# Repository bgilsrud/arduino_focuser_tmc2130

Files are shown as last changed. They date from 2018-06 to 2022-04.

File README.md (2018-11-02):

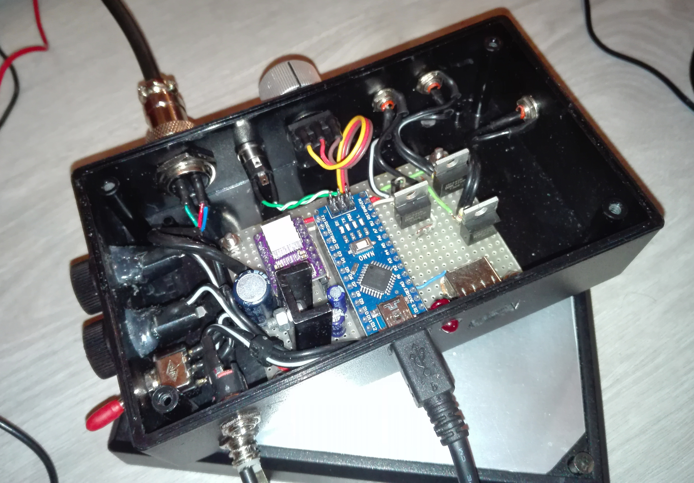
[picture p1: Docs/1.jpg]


# Arduino-based telescope focuser controller
Simple MoonLite-compatible motorized focuser controller. Thought to be used with INDI.
Doesn't support temperature compensation.
It also supports a non-official MoonLite-style command to change the state of all the
Arduino's digital and PWM pins: in my case I control two dew heaters and a fan to cool the primary mirror.

### MoonLite focuser
I use a Nema 11 motor that moves the focuser knob using a belt.
If you don't have a heavy focuser, also consider using a Nema 8.
A 20 teeth pulley and a 6mm wide 160mm long belt are enough.
Absolute and relative positioning, half and full step switching.

### Pin management
Define the customizable pins in the `CUSTOMIZABLE_PINS` array in the `Config.h` file and
upload the firmware.

#### AstroAllInOne
<a href="https://github.com/SquareBoot/AstroAllInOne">AstroAllInOne</a>
is this firmware's companion INDI driver that allows the end user to
change the state of **every** pin of the board (pay attention! **do not change the
state of the stepper motor driver's pins**). Refer to its documentation on
how to configure it. Without AstroAllInOne, the Arduino will behave just like
a generic MoonLite focuser controller.

### Polar finder illuminator
For my EQ5 I needed an illuminator and I added it to the focuser project.
It requires a potentiometer to dim the light and a red LED.
Can be easily disabled in the `Config.h` file by setting the `ENABLE_POLAR_LIGHT` field.

### Autodesk Eagle project
In the "Eagle" directory you can find the full circuit project, both schematics and PCB. 
It's the one I use for my telescope, but feel free to modify it to 
accomplish your necessities: for instance, you could add another dew heater controller, 
or remove the Newton mirror cooler MOSFET.
<br>**Made with Eagle 9.2.2 Premium**
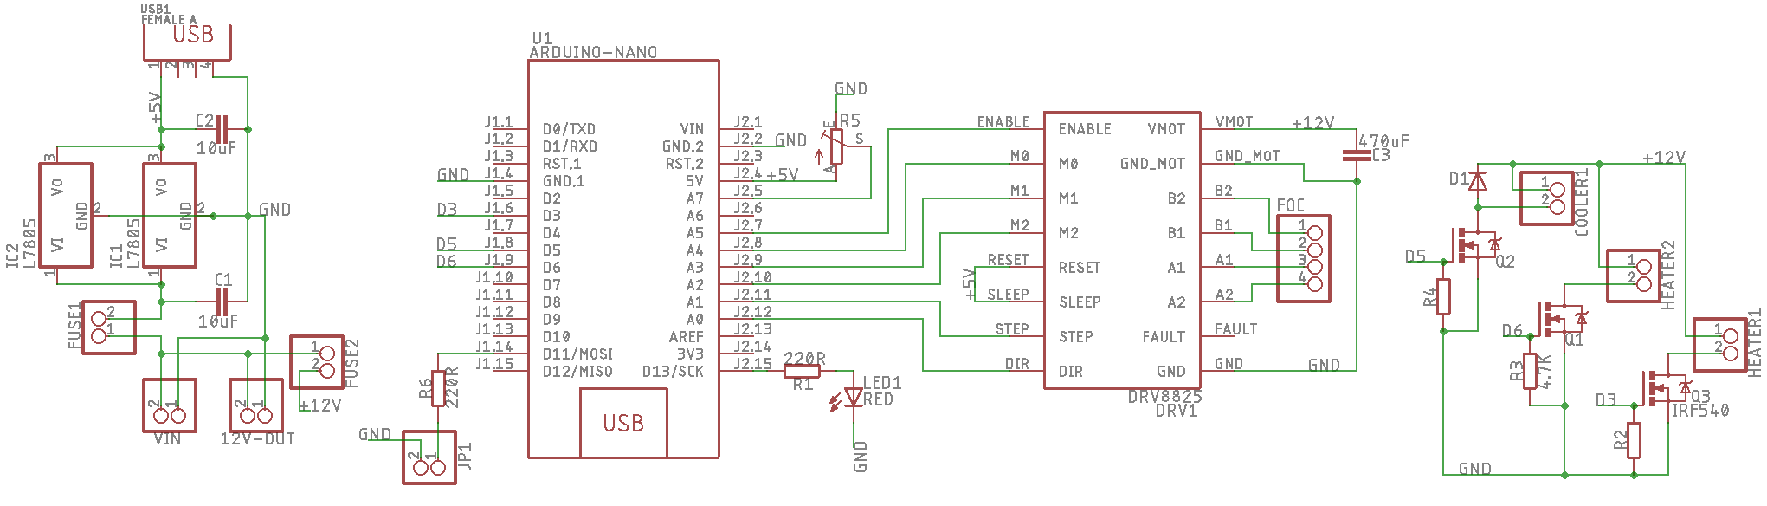
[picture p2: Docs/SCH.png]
<br>

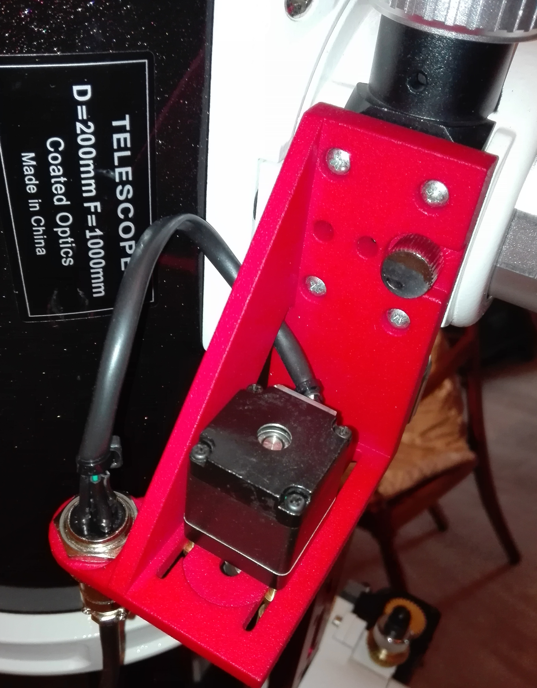
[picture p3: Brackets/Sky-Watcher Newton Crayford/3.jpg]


### Mounting brackets
I included the mounting brackets I made for the common SkyWatcher 
dual-speed Crayford focuser (I have a 200mm f/5 Newton OTA).

**AutoCAD 2019** project, STL and IGS exported files.

### Forking & issues
Feel free to submit pull requests! New brackets are welcome!

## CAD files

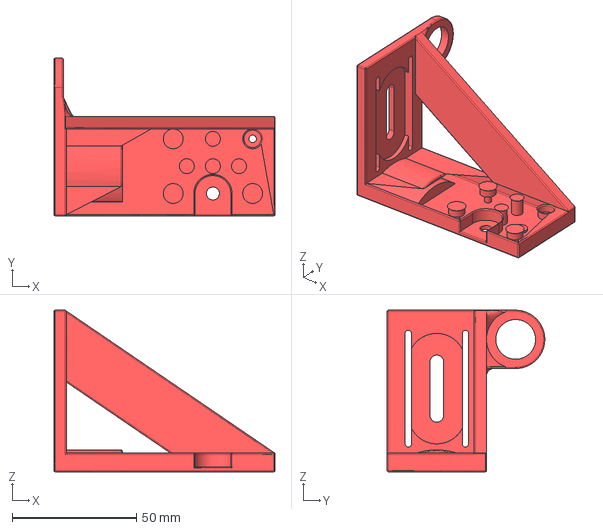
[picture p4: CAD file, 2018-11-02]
Brackets/Sky-Watcher Newton Crayford/IGS.igs
89.0 x 63.5 x 65.1 mm

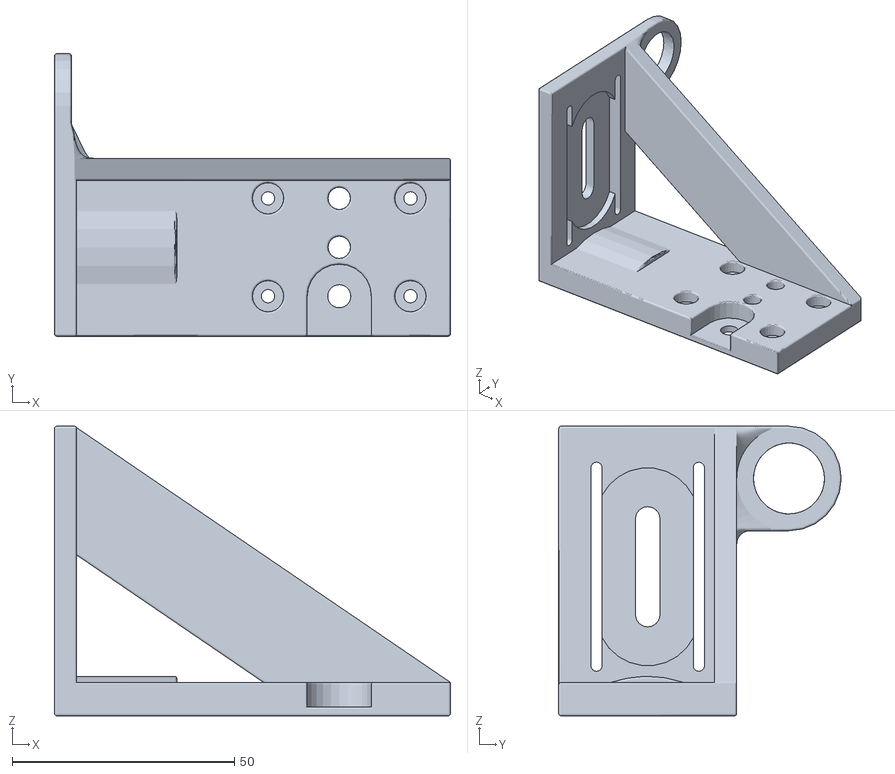
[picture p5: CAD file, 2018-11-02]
Brackets/Sky-Watcher Newton Crayford/STL.stl
89.0 x 63.5 x 65.1

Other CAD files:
Brackets/Sky-Watcher Newton Crayford/AutoCAD.dwg

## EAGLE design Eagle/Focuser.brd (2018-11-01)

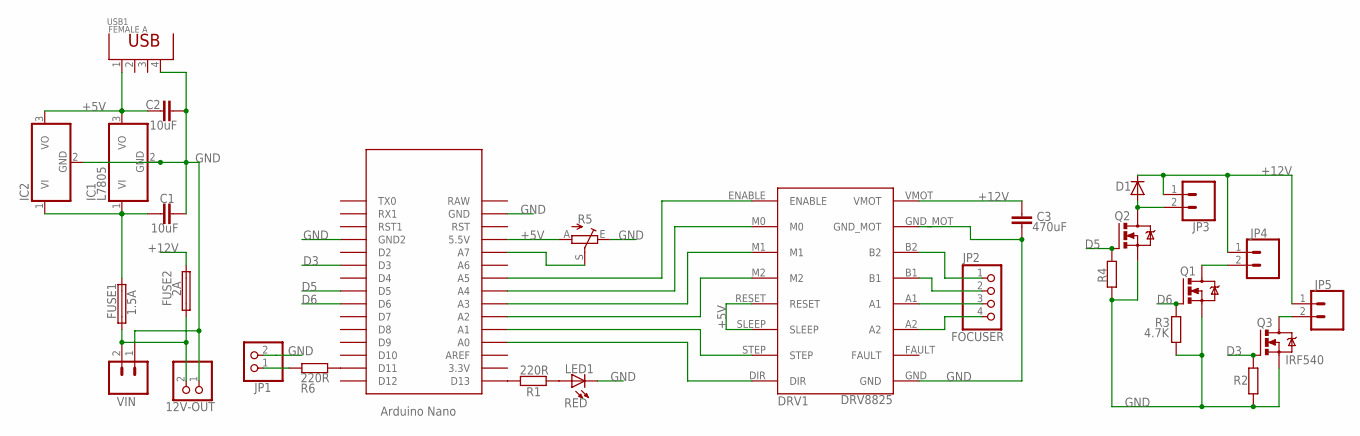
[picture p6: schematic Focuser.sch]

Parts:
12V-OUT: PINHD-1X2; 1X02
C1, C2: 10uF; C025-024X044
C3: 470uF; C5B2.5
D1: DIODE-D-2.5; D-2.5
DRV1: DRV8825
FUSE1: 1.5A; FUSE_HOLDER_5X20MM
FUSE2: 2A; FUSE_HOLDER_5X20MM
IC1, IC2: L7805; TO220V
JP1: PINHD-1X2; 1X02
JP2: FOCUSER; 1X04
JP3, JP4, JP5: CONN_025MM; SCREWTERMINAL-5MM-2
LED1: RED; LED3MM
Q1, Q2, Q3: IRF540; TO220BV
R1, R6: 220R; 0204/5
R2, R3, R4: 4.7K; 0204/5
R5: TRIM_EU-B64Y; B64Y
U$1: NANO
USB1: FEMALE A; USB4+2P-2.0-90D
VIN: CONN_025MM; SCREWTERMINAL-5MM-2

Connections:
+5V: C2.1, DRV1.RESET, DRV1.SLEEP, IC1.3 (VO), IC2.3 (VO), R5.A, U$1.5V (5.5V), USB1.1
+12V: C3.2, D1.C, DRV1.VMOT, FUSE2.2, JP3.1, JP4.1, JP5.1
D3: Q3.G, R2.2, U$1.D3
D5: Q2.G, R4.2, U$1.D5
D6: Q1.G, R3.2, U$1.D6
D13: R1.2, U$1.D13
GND: 12V-OUT.1, C1.2, C2.2, C3.1, DRV1.GND, DRV1.GND_MOT, IC1.2 (GND), IC2.2 (GND), JP1.2, LED1.K (C), Q1.S, Q2.S, Q3.S, R2.1, R3.1, R4.1, R5.E, U$1.GND, U$1.GND1 (GND2), USB1.4, VIN.1
unnamed: LED1.A, R1.1
unnamed: R5.S, U$1.A7
unnamed: R6.2, U$1.D11
unnamed: C1.1, FUSE1.2, IC1.1 (VI), IC2.1 (VI)
unnamed: DRV1.DIR, U$1.A0
unnamed: DRV1.ENABLE, U$1.A5
unnamed: 12V-OUT.2, FUSE1.1, FUSE2.1, VIN.2
unnamed: D1.A, JP3.2, Q2.D
unnamed: JP4.2, Q1.D
unnamed: JP5.2, Q3.D
unnamed: DRV1.STEP, U$1.A1
unnamed: DRV1.B2, JP2.1
unnamed: DRV1.B1, JP2.2
unnamed: DRV1.A1, JP2.3
unnamed: DRV1.A2, JP2.4
unnamed: DRV1.M2, U$1.A2
unnamed: DRV1.M1, U$1.A3
unnamed: JP1.1, R6.1
unnamed: DRV1.M0, U$1.A4

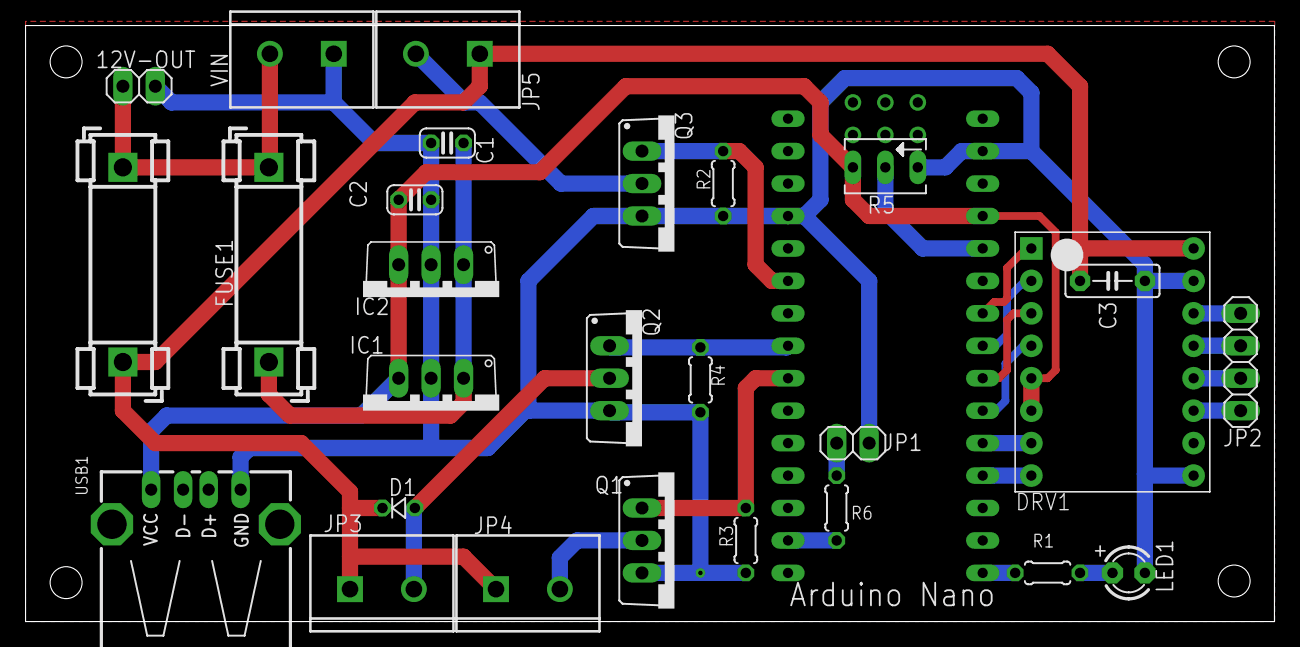
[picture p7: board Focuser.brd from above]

Board: 2 copper layers, 97.8 x 46.7 mm, 28 parts (0 on the bottom side), 26 nets.

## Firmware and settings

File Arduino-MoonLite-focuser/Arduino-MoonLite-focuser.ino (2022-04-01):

/*
  Moonlite-compatible focuser controller

  ** Version 2.2 **
    Bugs fixed, general changes.

  ** Version 2.1 **
    Added function to set pin value.

  ** Version 2.0 **
    Modified to be used with the cheaper DRV8825 (or A4988) driver and almost completely rewritten by SquareBoot

  ** Version 1.0 **
    Inspired by (http://orlygoingthirty.blogspot.co.nz/2014/04/arduino-based-motor-focuser-controller.html)
    Modified for INDI, easydriver by Cees Lensink
    Added sleep function by Daniel Franzén
*/

#include <Arduino.h>

// Firmware version - 2.2
const String VERSION = "22";

// Configuration
#include "Config.h"


// AVR libraries
#if ENABLE_SW_RS == true
#include <avr/io.h>                                       // AVR library
#include <avr/wdt.h>                                      // Watchdog timer
#define reboot() wdt_enable(WDTO_30MS); while(1) {}       // To reset the board, call reboot();
#endif

// Stepper driver libraries
// AccelStepper, used to provide motor acceleration
#include <AccelStepper.h>
#if STEPPER_TYPE == 0
#include <BasicStepperDriver.h>
#elif STEPPER_TYPE == 1
#include <DRV8825.h>
#elif STEPPER_TYPE == 2
#include <A4988.h>
#elif STEPPER_TYPE == 3
#include <DRV8834.h>
#elif STEPPER_TYPE == 4
#include <TMCStepperDriver.h>
#endif

// The period to wait before turning off the driver (in milliseconds)
boolean isRunning = false;
#ifdef DRIVER_EN
#define TIMER_DELAY 30000
boolean isPowerOn = false;
#endif
#if STEPPER_TYPE != 0
boolean isHalfStep = false;
#endif

#ifdef DRIVER_EN
#if STEPPER_TYPE == 0
BasicStepperDriver driver(STEPS_REV, DRIVER_DIR, DRIVER_STEP, DRIVER_EN);
#elif STEPPER_TYPE == 1
DRV8825 driver(STEPS_REV, DRIVER_DIR, DRIVER_STEP, MODE0, MODE1, MODE2, DRIVER_EN);
#elif STEPPER_TYPE == 2
A4988 driver(STEPS_REV, DRIVER_DIR, DRIVER_STEP, MODE0, MODE1, MODE2, DRIVER_EN);
#elif STEPPER_TYPE == 3
DRV8834 driver(STEPS_REV, DRIVER_DIR, DRIVER_STEP, MODE0, MODE1, DRIVER_EN);
#elif STEPPER_TYPE == 4
TMCStepperDriver driver(STEPS_REV, DRIVER_DIR, DRIVER_STEP, Axis1_CS, Axis1_SCK, Axis1_MISO, Axis1_MOSI);
//BasicStepperDriver driver(STEPS_REV, DRIVER_DIR, DRIVER_STEP, DRIVER_EN);

#endif
#else
#if STEPPER_TYPE == 0
BasicStepperDriver driver(STEPS_REV, DRIVER_DIR, DRIVER_STEP);
#elif STEPPER_TYPE == 1
DRV8825 driver(STEPS_REV, DRIVER_DIR, DRIVER_STEP, MODE0, MODE1, MODE2);
#elif STEPPER_TYPE == 2
A4988 driver(STEPS_REV, DRIVER_DIR, DRIVER_STEP, MODE0, MODE1, MODE2);
#elif STEPPER_TYPE == 3
DRV8834 driver(STEPS_REV, DRIVER_DIR, DRIVER_STEP, MODE0, MODE1);
#elif STEPPER_TYPE == 4
TMCStepperDriver driver(STEPS_REV, DRIVER_DIR, DRIVER_STEP, Axis1_CS, Axis1_SCK, Axis1_MISO, Axis1_MOSI);
//BasicStepperDriver driver(STEPS_REV, DRIVER_DIR, DRIVER_STEP);

#endif
#endif

long ml_to_stepper_pos(long ml)
{
    return ml * GEAR_RATIO;
}

long stepper_to_ml_pos(long stepper)
{
    return stepper / GEAR_RATIO;
}

// ----- Motor control wrappers -----
// Forward step
void goForward() {
  int n = SINGLE_STEP;
#if STEPPER_TYPE != 0
  if (isHalfStep) {
    n *= HALF_STEP;

  } else {
    n *= FULL_STEP;
  }
#endif
  driver.move(n);
}
// Backward step
void goBackward() {
  int n = SINGLE_STEP;
#if STEPPER_TYPE != 0
  if (isHalfStep) {
    n *= HALF_STEP;

  } else {
    n *= FULL_STEP;
  }
#endif
  driver.move(-n);
}
#if REVERSE_DIR == false
AccelStepper stepper(goForward, goBackward);
#else
AccelStepper stepper(goBackward, goForward);
#endif

#define CMD_LENGHT 8
// Used to interpret the MoonLite protocol
char inChar;
char cmd[CMD_LENGHT];
char param[CMD_LENGHT];
char line[CMD_LENGHT];
boolean eoc = false;
int idx = 0;
long timerStartTime = 0;
char tempString[10];

int customPins[] = CUSTOMIZABLE_PINS;
#define BLINK_PERIOD 300
boolean ledState = false;
long blinkStartTime = 0;

void setup() {
  // Serial connection
  Serial.begin(SERIAL_SPEED);
  // Status LED
  pinMode(LED, OUTPUT);
  // Customizable pins
  for (int i = 0; i < (sizeof(customPins) / sizeof(*customPins)); i++) {
    pinMode(customPins[i], OUTPUT);
  }
  // Polar finder light
#if ENABLE_POLAR_LIGHT == true
  pinMode(POLAR_LIGHT_LED, OUTPUT);
#endif

  //for (;;) Serial.println("hello");
  // ----- Motor driver -----
  // Ignore Moonlite speed

  driver.setup();
  driver.setRPM(MOTOR_RPM);
  //driver.begin(1,1);
  //stepper.setSpeed(MOTOR_PPS);
  //stepper.setMaxSpeed(MOTOR_PPS);
  stepper.setAcceleration(MOTOR_ACCEL);
  stepper.setMaxSpeed(MOTOR_RPM * STEPS_REV / 60);
#if STEPPER_TYPE != 0
  driver.setMicrostep(FULL_STEP);
#endif
  turnOff();

  blinkStartTime = millis();
  memset(line, 0, CMD_LENGHT);
}

void loop() {
  // Only have to do this if stepper is on
  if (isRunning) {
    stepper.run();
    if (stepper.distanceToGo() == 0) {
      // Start timer to decide when to power off the board
      timerStartTime = millis();
      isRunning = false;
    }
  }
#ifdef DRIVER_EN
  else if (isPowerOn) {
    // Turn power off if active time period has passed
    if (millis() - timerStartTime >= TIMER_DELAY) {
      turnOff();
    }
  }
#endif
  else {
    unsigned long currentMillis = millis();
    if (currentMillis - blinkStartTime >= BLINK_PERIOD) {
      blinkStartTime = currentMillis;
      ledState = !ledState;
      digitalWrite(LED, ledState);
    }
  }

#if ENABLE_POLAR_LIGHT == true
  int val = analogRead(POT_ANALOG_PIN);
  if (val > 20) {
    analogWrite(POLAR_LIGHT_LED, map(val, 20, 1023, 0, 250));

  } else {
    analogWrite(POLAR_LIGHT_LED, 0);
  }
#endif

  // Read the command until the terminating # character
  while (Serial.available() && !eoc) {
    inChar = Serial.read();
    if (inChar != '#' && inChar != ':') {
      line[idx++] = inChar;
      if (idx >= CMD_LENGHT) {
        idx = CMD_LENGHT - 1;
      }

    } else {
      if (inChar == '#') {
        eoc = true;
      }
    }
  }

  // We may not have a complete command set but there is no character coming in for now and mightas well loop in case stepper needs updating
  // eoc will flag if a full command is there to act upon
  // Process the command we got
  if (eoc) {
    memset(cmd, 0, CMD_LENGHT);
    memset(param, 0, CMD_LENGHT);

    // Set the value of a pin
    if ((line[0] == 'A') && (line[1] == 'V')) {
      String pin = "";
      pin.concat(line[2]);
      pin.concat(line[3]);
      String value = "";
      value.concat(line[4]);
      value.concat(line[5]);
      value.concat(line[6]);
      int p = pin.toInt();
      for (int i = 0; i < (sizeof(customPins) / sizeof(*customPins)); i++) {
        if (customPins[i] == p) {
          analogWrite(p, value.toInt());
          break;
        }
      }
    }

    int len = strlen(line);
    if (len >= 2) {
      strncpy(cmd, line, 2);
    }
    if (len > 2) {
      strncpy(param, line + 2, len - 2);
    }

    memset(line, 0, CMD_LENGHT);
    eoc = false;
    idx = 0;

    // Execute the command
    // The stand-alone program sends :C# :GB# on startup
    // :C# is a temperature conversion, doesn't require any response

    // LED backlight value, always return "00"
    if (!strcasecmp(cmd, "GB")) {
      Serial.print("00#");
    }

    if (!strcasecmp(cmd, "RS")) {
#if ENABLE_SW_RS == true
      reboot();
#else
      for (int i = 0; i < (sizeof(customPins) / sizeof(*customPins)); i++) {
        analogWrite(customPins[i], 0);
      }
#endif
    }

    // Immediately stop any focus motor movement. Returns nothing
    if (!strcasecmp(cmd, "FQ")) {
      if (!isRunning) {
        turnOn();
      }
      // Stop as fast as possible
      stepper.stop();
      // Blocks until the target position is reached and stopped
      //stepper.runToPosition();
    }

    // Go to the new position as set by the ":SNYYYY#" command. Returns nothing.
    // Turn stepper on and flag it is running
    // is this the only command that should actually make the stepper run ?
    if (!strcasecmp(cmd, "FG")) {
      if (!isRunning) {
        turnOn();
      }
    }

    // Returns the temperature coefficient where XX is a two-digit signed (2’s complement)  number.
    if (!strcasecmp(cmd, "GC")) {
      Serial.print("02#");
    }

    // Returns the current stepping delay where XX is a two-digit unsigned  number. See the :SD# command for a list of possible return values.
    // Might turn this into AccelStepper acceleration at some point
    if (!strcasecmp(cmd, "GD")) {
      Serial.print("02#");
    }

    // Returns "FF#" if the focus motor is half-stepped otherwise return "00#"
    if (!strcasecmp(cmd, "GH")) {
#if STEPPER_TYPE != 0
      if (isHalfStep) {
        Serial.print("FF#");

      } else {
        Serial.print("00#");
      }
#else
      Serial.print("00#");
#endif
    }

    // Returns "00#" if the focus motor is not moving, otherwise return "01#",
    // AccelStepper returns Positive as clockwise
    if (!strcasecmp(cmd, "GI")) {
      if (stepper.distanceToGo() == 0) {
        Serial.print("00#");

      } else {
        Serial.print("01#");
      }
    }

    // Returns the new position previously set by a ":SNYYYY" command where YYYY is a four-digit unsigned hex number.
    if (!strcasecmp(cmd, "GN")) {
      sprintf(tempString, "%04X", stepper_to_ml_pos(stepper.targetPosition()));
      Serial.print(tempString);
      Serial.print("#");
    }

    // Returns the current position where YYYY is a four-digit unsigned hex number.
    if (!strcasecmp(cmd, "GP")) {
      sprintf(tempString, "%04X", stepper_to_ml_pos(stepper.currentPosition()));
      Serial.print(tempString);
      Serial.print("#");
    }

    // Returns the current temperature where YYYY is a four-digit signed (2’s complement) hex number.
    if (!strcasecmp(cmd, "GT")) {
      Serial.print("0020#");
    }

    // Get the version of the firmware as a two-digit decimal number where the first digit is the major version number, and the second digit is the minor version number.
    if (!strcasecmp(cmd, "GV")) {
      Serial.print(VERSION + '#');
    }

    // Set the new temperature coefficient where XX is a two-digit, signed (2’s complement) hex number.
    if (!strcasecmp(cmd, "SC")) {

    }

    // Set the new stepping delay where XX is a two-digit,unsigned hex number.
    if (!strcasecmp(cmd, "SD")) {

    }

    // Set full-step mode.
#if STEPPER_TYPE != 0
    if (!strcasecmp(cmd, "SF")) {
      driver.setMicrostep(FULL_STEP);
      isHalfStep = false;
    }
#endif

    // Set half-step mode.
#if STEPPER_TYPE != 0
    if (!strcasecmp(cmd, "SH")) {
      driver.setMicrostep(HALF_STEP);
      isHalfStep = true;
    }
#endif

    // Set the new position where YYYY is a four-digit
    if (!strcasecmp(cmd, "SN")) {
      // stepper.enableOutputs(); // Turn the motor on here?
      if (!isRunning) {
        turnOn();
      }
      stepper.moveTo(ml_to_stepper_pos(hexToLong(param)));
    }

    // Set the current position, where YYYY is a four-digit unsigned hex number.
    if (!strcasecmp(cmd, "SP")) {
      stepper.setCurrentPosition(ml_to_stepper_pos(hexToLong(param)));
    }
    if (!strcasecmp(cmd, "GS")) {
      sprintf(tempString, "%08X", driver.status());
      Serial.print(tempString);
      Serial.print("#");
    }
  }
}

long hexToLong(char *line) {
  return strtol(line, NULL, 16);
}

void turnOn() {
#ifdef DRIVER_EN
  driver.enable();
  isPowerOn = true;
#endif
  digitalWrite(LED, HIGH);
  isRunning = true;
}

void turnOff() {
#ifdef DRIVER_EN
  driver.disable();
  isPowerOn = false;
#endif
  isRunning = false;
}

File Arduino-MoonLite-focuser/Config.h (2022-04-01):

// ----- General config -----
#ifndef CONFIG_H
#define CONFIG_H
// Status LED pin
#define LED 2
#define SERIAL_SPEED 115200
#define ENABLE_SW_RS false

// ----- Stepper driver configuration -----
#define STEPS_REV 2038
#define GEAR_RATIO (90/14)
// Motor driver type: BasicStepperDriver (0), DRV8825 (1), A4988 (2), DRV8834 (3), or TMC2130 (4)
#define STEPPER_TYPE 4
// Steps per revolution
#define SINGLE_STEP 1
// Ignored for BasicStepperDriver. Can be 1, 2, 4, 8, 16 or 32
#define FULL_STEP 1
// Ignored for BasicStepperDriver. Can be 1, 2, 4, 8, 16, 32, 64, 128, or 256
#define HALF_STEP 2
// Reverses the direction of the motor
#define REVERSE_DIR false
// RPM. Decreasing this value should decrease telescope shaking.
#define MOTOR_RPM 20
// Acceleration
#define MOTOR_ACCEL 100
// Motor pulses per second (pps). See full formula here: https://electronics.stackexchange.com/a/232679
// #define MOTOR_PPS (MOTOR_RPM * STEPS_REV / 60)
// ----- Driver pins -----
// Driver DIR pin
#define DRIVER_DIR PB2
// Driver STEP pin
#define DRIVER_STEP PB10
// Driver ENABLE pin. Comment to disable functionality
//#define DRIVER_EN 4
// M0. Only for microstepping-enabled drivers
#define MODE0 7
// M1. Only for microstepping-enabled drivers
#define MODE1 8
// M2. Only for microstepping-enabled drivers
#define MODE2 11

// ----- Polar finder light -----
#define ENABLE_POLAR_LIGHT true
#define POT_ANALOG_PIN 0
#define POLAR_LIGHT_LED 10

// ----- Customizable pins -----
// List of pins that can be modified by the serial port
#define CUSTOMIZABLE_PINS {5, 6, 9}

// Axis1 RA/Azm step/dir driver
#define Axis1_MOSI          PA7 //17
#define Axis1_SCK           PA5 //15     // SPI SCK
#define Axis1_CS            PA1 //11     // SPI CS
#define Axis1_MISO          PA6 //16     // SPI MISO
#define Axis1_STEP          PB10 //21     // Step
#define Axis1_DIR           PB2 //20     // Dir
#define Axis1_IRUN          200

#endif

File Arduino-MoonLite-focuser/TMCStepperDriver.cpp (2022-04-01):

/*
 * TMCStepperDriver

 * Copyright (C)2015 Laurentiu Badea
 * Copyright (C)2022 Ben Gilsrud
 *
 * This file may be redistributed under the terms of the MIT license.
 * A copy of this license has been included with this distribution in the file LICENSE.
 */
#include "TMCStepperDriver.h"
#include "Config.h"
#include "TMC_SPI.h"

TMCStepperDriver::TMCStepperDriver(int steps, int dir_pin, int step_pin, int cs_pin, int sck_pin, int miso_pin, int mosi_pin)
    :BasicStepperDriver(steps, dir_pin, step_pin),tmc_spi(cs_pin, sck_pin, miso_pin, mosi_pin, TMC2130, AXIS1_DRIVER_RSENSE)
{
    //Serial.println("hello from tmcstepperdriver");
//./OnStep.ino:    tmcAxis3.setup(AXIS3_DRIVER_INTPOL,AXIS3_DRIVER_DECAY_MODE,AXIS3_DRIVER_CODE,axis3Settings.IRUN,axis3Settings.IRUN);

}

void TMCStepperDriver::setup()
{
    tmc_spi.setup(true, STEALTHCHOP, 1, Axis1_IRUN, Axis1_IRUN * .5);
}

/*
 * Set microstepping mode (1:divisor)
 * Allowed ranges for TMCStepperDriver are 1:1 to 1:32
 * If the control pins are not connected, we recalculate the timing only
 *
 */
short TMCStepperDriver::setMicrostep(short microsteps)
{
    /* FIXME */
    uint8_t chopconf;
    if (microsteps == 1)
        chopconf = 8;
    else if (microsteps == 2)
        chopconf = 7;
    else if (microsteps == 4)
        chopconf = 6;
    else if (microsteps == 8)
        chopconf = 5;
    else if (microsteps == 16)
        chopconf = 4;
    else if (microsteps == 32)
        chopconf = 3;
    else if (microsteps == 64)
        chopconf = 2;
    else if (microsteps == 128)
        chopconf = 1;
    else if (microsteps == 256)
        chopconf = 0;

    if (tmc_spi.refresh_CHOPCONF(chopconf))
        this->microsteps = microsteps;

    return this->microsteps;
}

short TMCStepperDriver::getMaxMicrostep(){
    return TMCStepperDriver::MAX_MICROSTEP;
}

uint32_t TMCStepperDriver::status(void)
{
    return tmc_spi.refresh_DRVSTATUS();
}

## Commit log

2018-02-26 Added drawings
    [Bracket and pulley.dwg]
2018-02-26 Arduino code rewritten to work with StepSticks
    I changed almost everything...
    [SkyWatcher-Newton-200.dwg]
2018-02-27 Updated brackets
    [3D.stl, AutoCAD.dwg, SkyWatcher-Newton-200.dwg]
2018-03-30 Added Eagle files, new brackets, Arduino firmware update
    [3D.stl, AutoCAD.dwg, SCH.brd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]
2018-04-01 Move sketch to appropriately named subfolder
    The Arduino IDE requires that a sketch be located in a folder of the same name. Although the name of the repository does match the sketch name, when GitHub's popular Clone or download > Download ZIP 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
    When opening a file that does not meet this sketch/folder name matching requirement the Arduino IDE presents a dialog:
    The file "Arduino-MoonLite-focuser.ino" needs to be inside a sketch folder named "Arduino-MoonLite-focuser".
    Create this folder, move the file, and continue?
    After clicking "OK" the Arduino IDE currently moves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
2018-04-01 Added README, LICENSE, brackets updated
    [3D.stl, AutoCAD.dwg, IGS.igs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]
2018-06-17 Added photos, Arduino SW update
    [SCH.brd, SCH.sch]
2018-09-22 New PCB design
    [SCH.brd, SCH.sch]
2018-09-22 PCB ground plane added
    [SCH.brd]
2018-09-22 Update PCB
    [SCH.brd]
2018-11-02 Update with new brackets
    [AutoCAD.dwg, IGS.igs, STL.stl]
2022-04-01 fix irun, scale steps, fix limit
    [Arduino-MoonLite-focuser.ino, Config.h, TMCStepperDriver.cpp]

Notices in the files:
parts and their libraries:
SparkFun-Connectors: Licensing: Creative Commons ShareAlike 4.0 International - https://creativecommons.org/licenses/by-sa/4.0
